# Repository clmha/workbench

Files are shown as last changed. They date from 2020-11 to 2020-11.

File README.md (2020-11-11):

# Établi de menuisier
Ce projet est un établi de menuisier (code de projet WB1) pour la réalisation de meubles de dimensions moyennes comme une table de chevet, un petit bureau, mais pas une table de cuisine.

Il est construit avec des matériaux aux dimensions courantes en Amérique du Nord et des méthodes de fixation simples.

D'un côté de l'établi, sur la face avant, le plan de travail affleure les pattes de l'établi afin de pouvoir fixer des panneaux à la verticale et utiliser un étau de menuisier. De l'autre côté, il dépasse de 3" afin de permettre l'utilisation de serre-joints.
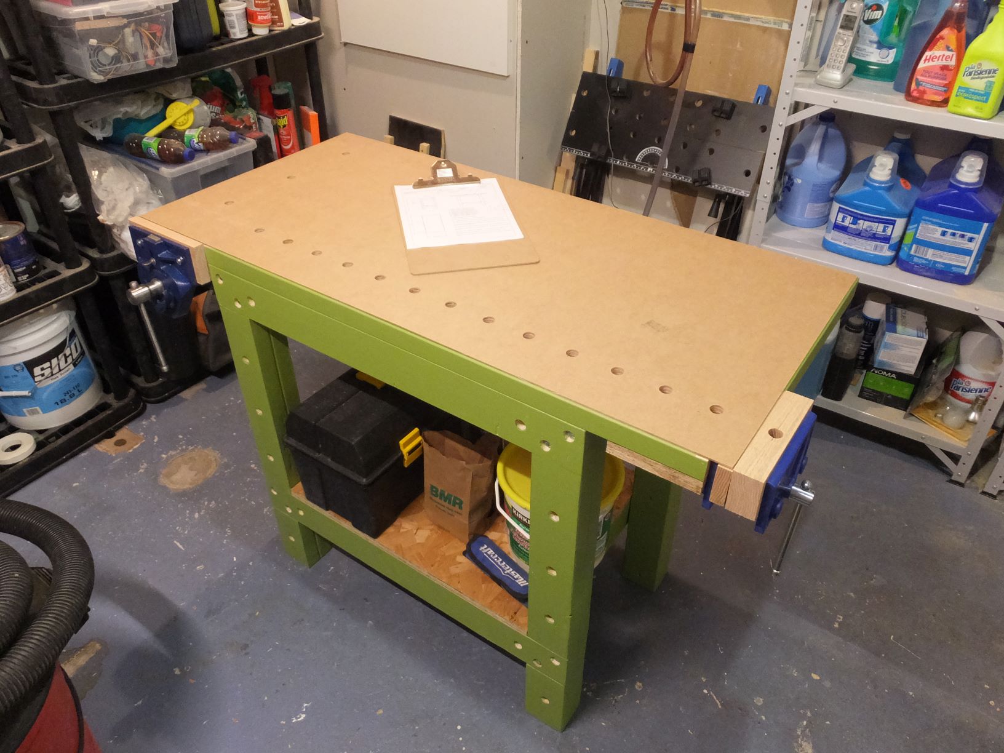
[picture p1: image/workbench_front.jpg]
Résultat final vu de face
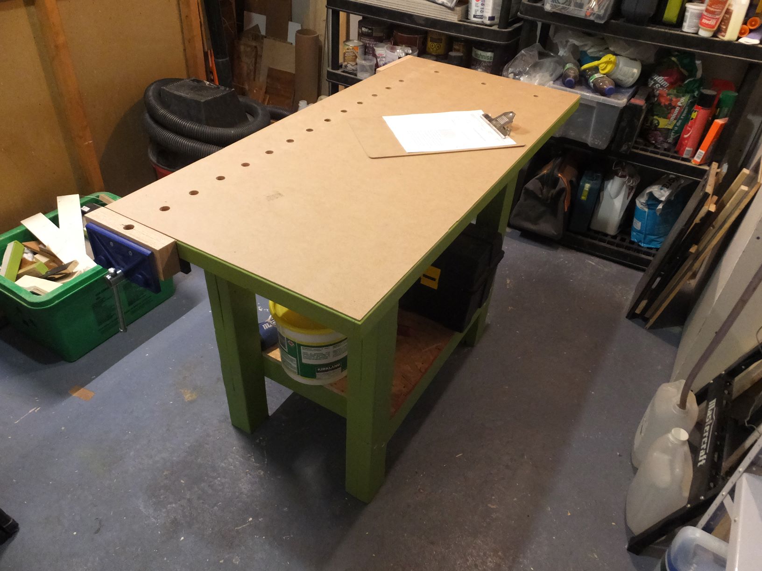
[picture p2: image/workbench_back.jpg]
Résultat final vu de dos
 

# Matériaux
Si vous ne faites aucune erreur de coupe, vous aurez besoin de :

* (1) Madrier 2x3x8'
* (5) Madrier 2x4x8'
* (2) Panneau de contreplaqué 3/4"x2'x4'
* (1) Panneau d'OSB 3/4"x2'x4'
* (1) Panneau dur 1/8"x2'x4'

L'établi en photo a été réalisé en épinette.

# Quincaillerie
Hormis les étaux, vous aurez besoin de :

* (16) Tire-fond 1/4"x2 1/2"
* (16) Rondelle plate 1/4"
* Clous 1 1/2"
* Clous de finition 1 1/4"
* Clous de finition 1 1/2"
* Colle à bois
* Vis à bois #8 1 1/4"
* Vis à bois #8 2 1/2"
* Vis pour trou en angle #8 2 1/2"

# Outils nécessaires
Hormis les outils de base (p. ex. ruban à mesurer), vous aurez également besoin de :

* Banc de scie pour découper les moulures;
* Gabarit pour faire des trous en angle;
* Perceuse/visseuse;
* Scie à onglet pour découper précisement les madriers;
* Scie circulaire pour découper les panneaux.

# Liste des documents
* WB1-ASY-001.pdf : dessin d'ensemble du projet avec la liste des pièces;
* WB1-MFG-001.pdf : le coût du projet (estimé et réel);
* WB1-MFG-002.pdf : la fiche de débit;
* WB1-PRT-XYZ.pdf : le dessin de définition de la pièce numéro XYZ (notez que les pièces triviales n'ont pas de dessin de définition);
* WB1-REQ-001.pdf : le cahier des charges.

# Environnement de développement
* Windows 10 comme système d'exploitation;
* QCAD Professional pour les dessins techniques;
* LibreOffice 6.* pour les documents;
* PDFtk pour manipuler les fichiers PDF;
* Visual Studio Build Tools 2019 pour les outils de développement de base.

# Construire les artefacts
Avec l'environnement de développement correct, il vous suffit de lancer la commande "nmake" depuis une invite de commande de développeur pour Visual Studio 2019 ("Developer Command Prompt for VS 2019") à la racine du projet. Les documents seront générés dans le répertoire "build".

En cas d'erreurs "'X' n'est pas reconnu en tant que commande interne ou externe [...]", vérifiez que les exécutables de LibreOffice, QCAD, PDFtk sont dans votre PATH.

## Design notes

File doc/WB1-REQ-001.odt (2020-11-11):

Cahier des charges

WB1-REQ-001

Clément Hamel

2020-11-03

# Définitions

pi Pied

po Pouce

# Vision

Nous souhaitons dans notre atelier du sous-sol de 7 pi×8 pi un établi de menuiserie central qui permette à l’utilisateur de tourner tout autour de la pièce qu’il assemble. De plus, un côté sera dédié à la découpe, tandis que l’autre permettra de travailler sur les 3 côtés des planches découpées.

# Exigences

## Longueur

La longueur de l’Établi doit être de 4 pi ou inférieure.

Cela correspond à la longueur disponible de l’atelier (8 pi) avec 2 pi de libre de chaque côté.

## Largeur

La largeur de l’Établi doit être de 2 pi ou inférieur.

Cela correspond à la largeur disponible de l’atelier (7 pi) moins 2 pi de libre de chaque côté et moins 1 pi de réservé pour des rangements.

## Plan de travail

### Épaisseur

Le plan de travail de l’Établi doit avoir une épaisseur minimale de 1 1/2 po afin d’être suffisamment solide pour y fixer des accessoires de menuiserie (p. ex. un étau, des « bench dogs »).

### Hauteur

La hauteur du plan de travail de l’Établi doit être de 34 po par rapport au sol.

Cette hauteur correspond approximativement à la hauteur des premières phalanges de la main de l’utilisateur lorsque ses bras sont le long du corps et permet une utilisation hybride outils manuels/outils électriques.

## Fonctionnalités

### Verrouiller à plat

L’Établi doit permettre sur le côté avant du plan de travail d’utiliser des serre-joints en F de maximum 18 po pour verrouiller à plat :

- des panneaux de 3/4 po×2 pi×4 pi; ou
- des planches de 3/4 po×11 1/4 po×8 pi.

Cela correspond aux plus grands matériaux sur lesquels nous devons travailler à plat.

### Verrouiller à la verticale

L’Établi doit permettre de verrouiller à la verticale à l’arrière du plan de travail, à l’aide de serre-joints ou d’un étau, des panneaux de 1,5 po×2 pix4 pi de telle sorte qu’un de leurs chants arase le plan de travail ou dépasse de 3,5 po maximum.

Cela correspond aux plus grands matériaux sur lesquels nous devons travailler à la verticale.

## Étau d’établi

L’Établi doit permettre de fixer à l’arrière droite du plan de travail un étau d’établi avec des mâchoires de 7 po et une ouverture de 8 po.

## Finition

### Base

La base de l’Établi doit être peinte afin de protéger le bois de la moisissure et cacher ses imperfections.

### Plan de travail

Le plan de travail de l’Établi doit être brut afin d’éviter de déteindre/contaminer les pièces sur lesquelles l’utilisateur travaille.

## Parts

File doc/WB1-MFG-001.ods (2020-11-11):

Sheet: Planifié
Item | Qté | Source | Prix unitaire HT | Rabais | Prix HT | Remarques
Madrier 2x4x8’ d’EPS no 2 | 5 | (Estimation) | 6,49 $ |  | 32,45 $
Madrier 2x3x8’ d’EPS no 2 | 1 | (Estimation) | 3,59 $ |  | 3,59 $
Panneau de contreplaqué d’épinette 3/4"x2’x4’ standard | 2 | (Estimation) | 11,49 $ |  | 22,98 $
Panneau d’OSB 3/4"x2’x4’ | 1 | (Estimation) | 9,75 $ |  | 9,75 $
Panneau dur 1/8"x2’x4’ | 1 | (Estimation) | 4,99 $ |  | 4,99 $
Clous de finition 1 1/4" BT700 | 1 | (Estimation) | 7,99 $ |  | 7,99 $
Clous de finition 1 1/2" BT450 | 1 | (Estimation) | 6,69 $ |  | 6,69 $
Clous 1 1/2" ~500g | 1 | (Estimation) | 8,00 $ |  | 8,00 $
Tire-fond 1/4"x2 1/2" | 16 | (Estimation) | 0,24 $ |  | 3,84 $
Rondelle plate 1/4" | 16 | (Estimation) | 0,07 $ |  | 1,12 $
Vis à bois #8 1 1/4" BT100 | 1 | (Estimation) | 5,99 $ |  | 5,99 $
Vis à bois #8 2 1/2" BT100 | 1 | (Estimation) | 9,69 $ |  | 9,69 $
Vis pour trou en angle à gros filet #8 2 1/2" BT50 | 1 | (Estimation) | 7,74 $ |  | 7,74 $
Peinture 1 qt | 1 | (Estimation) | 25,00 $ |  | 25,00 $
Apprêt scelleur 1 qt | 1 | (Estimation) | 20,00 $ |  | 20,00 $
Sous-total HT |  |  |  |  | 169,82 $
TPS |  |  |  |  | 8,49 $
TVQ |  |  |  |  | 16,94 $
Total TTC |  |  |  |  | 195,25 $

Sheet: TQC
Item | Qté | Source | Prix unitaire HT | Rabais | Prix HT | Remarques
Madrier 2x4x8’ d’EPS no 2 | 4 | BMR | 6,49 $ |  | 25,96 $
Madrier 2x4 d’EPS |  | (Rebut) |  |  | 0,00 $
Madrier 2x3x8’ d’EPS no 2 | 1 | BMR | 3,59 $ |  | 3,59 $
Panneau de contreplaqué d’épinette 3/4"x2’x4’ standard | 2 | BMR | 11,49 $ |  | 22,98 $
Panneau d’OSB 3/4" |  | (Rebut) |  |  | 0,00 $
Panneau dur 1/8"x2’x4’ | 1 | BMR | 4,99 $ |  | 4,99 $
Clous de finition 1 1/4" |  | (Stock) |  |  | 0,00 $
Clous de finition 1 1/2" |  | (Stock) |  |  | 0,00 $
Clous vrillés 1 1/2" |  | (Stock) |  |  | 0,00 $
Tire-fond 1/4"x2 1/2" | 16 | BMR | 0,24 $ |  | 3,84 $
Rondelle plate 1/4" | 10 | (Stock) |  |  | 0,00 $
Rondelle plate 1/4" | 6 | BMR | 0,07 $ |  | 0,42 $
Vis à bois #8 1 1/4" |  | (Stock) |  |  | 0,00 $
Vis à bois #8 2 1/2" |  | (Stock) |  |  | 0,00 $
Vis pour trou en angle à gros filet #8 2 1/2" BT50 | 1 | Home Depot | 7,74 $ |  | 7,74 $
Peinture acrylique 1 gal | 1 | Sherwin-Williams | 5,00 $ |  | 5,00 $ | Rebut du détaillant de peinture.
Apprêt scelleur à l’alkyde |  | (Stock) |  |  | 0,00 $
Sous-total HT |  |  |  |  | 74,52 $
TPS |  |  |  |  | 3,73 $
TVQ |  |  |  |  | 7,43 $
Total TTC |  |  |  |  | 85,68 $

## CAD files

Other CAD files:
drawing/WB1-PRT-004.dxf
drawing/WB1-MFG-002.dxf
drawing/WB1-ASY-001.dxf

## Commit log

2020-06-08 Importating de la conception préliminaire
    Importe le dessin d'ensemble, la vue éclatée et la liste des pièces.
    [WB1-ASY-001.dxf, WB1-ASY-002.dxf]
2020-08-17 Provisions pour un étau
    Ajoute 8" entre les jambes et le bord du plateau de l'établi pour pouvoir accueuillir un petit étau d'établi frontal.
    Les petits étaux d'établi de menuisier semblent faire entre 6 1/2" et 7", donc 8" devrait être suffisant.
    [WB1-ASY-001.dxf]
2020-08-18 MàJ des pièces
    Ajoute la liste des pièces au dessin d'ensemble et supprime les documents obsolètes.
    [WB1-ASY-001.dxf, WB1-ASY-002.dxf]
2020-08-18 Diminution du nombre de pièces et des coûts
    Change la conception pour avoir un seul numéro de pièce pour le tablier avant et arrière et utilise une tablette plus mince.
    [WB1-ASY-001.dxf]
2020-08-19 Conception préliminaire et structure standard de projet
    Met à jour le dessin d'ensemble avec des moulures sur le bord du plateau pour protéger le chant du contreplaqué et ajoute les différentes méthodes de fixation envisagées.
    Ajoute une première estimation des coût (WB1-MFG-001), sans tenir compte de la finition pour le moment.
    Sépare les fichiers entre les dessins et les documents de bureautique et ajoute le Makefile pour générer les PDF.
    [WB1-ASY-001.dxf, WB1-MFG-001.ods]
2020-08-22 Estimation des 2x4
    Créé un plan de coupe (WB1-MFG-002) et ajoute l'estimation des coûts (WB1-MFG-001) les madriers qu'il manquait.
    Met aussi à jour les dimensions des sections des pièces qui étaient erronées dans le dessin d'ensemble (WB1-ASY-001).
    [WB1-MFG-001.ods, WB1-MFG-002.dxf]
2020-08-22 Ajout des dimensions générales au dessin d'ensemble
    [WB1-ASY-001.dxf]
2020-08-22 Ajout des panneaux au plan de coupe
    [WB1-MFG-002.dxf]
2020-08-22 MàJ pour les moulures et le stock
    Acheter les moulures déjà faites coûtait beaucoup trop cher versus les faire soi-même en refendant un madrier.
    Cette révision met à jour le plan de coupe et l'estimation des coûts en conséquence.
    De plus, après vérification des stocks, certaines fixations sont passées de "estimation" à "en stock" dans l'estimation (rondelles, colle et vis).
    [WB1-MFG-001.ods, WB1-MFG-002.dxf]
2020-08-22 Correction de la mise en page
    [WB1-MFG-002.dxf]
2020-08-23 Diminution de la longueur de l'entretoise supérieure avant
    Cela permettra d'utiliser des serre-joints plus facilement à l'avant.
    [WB1-ASY-001.dxf, WB1-MFG-002.dxf]
2020-08-23 MàJ du coût de la finition v.s. les stocks
    [WB1-MFG-001.ods]
2020-08-24 MàJ de la fixation des pattes
    Utilise des vis plutôt que des clous vrillés afin de pouvoir utiliser le stock.
    [WB1-ASY-001.dxf, WB1-MFG-001.ods]
2020-08-25 Suppression de la pièce no 13
    Les entretoises supérieures ont à nouveau la même longueur à l'avant et à l'arrière tout en permettant d'utiliser des serre-joint sur tout le pourtour excepté l'arrière.
    [WB1-ASY-001.dxf, WB1-MFG-002.dxf]
2020-08-26 Simplification de la conception
    Suppression des trous dans le plateau. Les "bench dogs" seront mieux fait ad hoc plutôt que d'essayer de deviner a priori leur emplacement.
    Dégagement de l'espace à gauche et à droite pour pouvoir installer des étaux d'établis.
    La base de l'établi est maintenant symétrique, permattant d'avoir le même PN pour les traverses et les entretoises, et a été rétrécie pour maximiser la capacité à utiliser des serre-joints sur le pou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
    La tablette ré-utilise un panneau de particule de récupération.
    [WB1-ASY-001.dxf, WB1-MFG-001.ods, WB1-MFG-002.dxf]
2020-08-26 Ajout du cahier des charges
2020-09-19 Optimisation des 2x4
    Nous avons maintenant besoin de 5 mcx de 2x4x8' (contre 6 auparavant).
    Le coût du projet a été mis à jour avec la peinture qui a été achetée et les 2x4 de rebut.
    [WB1-MFG-001.ods, WB1-MFG-002.dxf]
2020-10-03 MàJ Makefile pour nmake
    Profite de l'occasion pour le simplifier.
2020-10-03 Renomme le plan de coupe "fiche de débit"
    [WB1-MFG-002.dxf]
2020-10-10 MàJ des prix des matériaux
    [WB1-MFG-001.ods]
2020-10-13 Ajout du dessin de définition de la pièce no 4
    Le perçage des trous pour les tire-fonds n'est pas si trivial.
    [WB1-PRT-004.dxf]
2020-10-13 MàJ des coûts
    Finalement, il fallait plus de colle.
    [WB1-MFG-001.ods]
2020-10-27 MàJ des dépenses
    Achat des étaux d'établi et de la quincaillerie.
    [WB1-MFG-001.ods]
2020-11-01 MàJ du coût du projet
    [WB1-MFG-001.ods]
2020-11-01 Utilise l'arrière de l'établi comme vue principale
    C'est l'arrière de l'établi qui est le plus complexe avec les trous pour les "bench dogs", il mérite dont d'être la vue principale du dessin d'ensemble.
    En profite pour corriger des oublis dans les matériaux et les pièces qui ont été utilisés pour fixer les étaux.
    [WB1-ASY-001.dxf, WB1-MFG-001.ods]
2020-11-01 Corrige l'identification des pièces no 8 et 9
    [WB1-ASY-001.dxf]
2020-11-02 MàJ du coût après assemblage final
    Les étaux ont été montés, le plan de travail, la tablette et la protection fixés.
    [WB1-MFG-001.ods]
2020-11-04 MàJ TQC
    Enlève les détails du coût des étaux et de leur installation car ils sont des accessoires.
    Corrige les dessins pour les matériaux et les fixations qui ont été utilisés au final.
    Enlève le statu de brouillon aux documents et aux dessins.
    [WB1-ASY-001.dxf, WB1-MFG-001.ods, WB1-MFG-002.dxf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]
2020-11-11 Description du projet TQC
    Ajoute les photos et en profite pour corriger quelques petites erreurs dans le coût du projet. Nous ne sommes pas obligés d'utiliser des clous vrillés 1 1/2", des clous communs peuvent faire l'affaire.
    [WB1-MFG-001.ods]
2020-11-11 Remplace "de menuiserie" par "de menuisier"
